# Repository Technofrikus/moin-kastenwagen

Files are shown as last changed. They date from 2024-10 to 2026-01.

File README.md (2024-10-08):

# Moinboards Kastenwagen Alu PCB

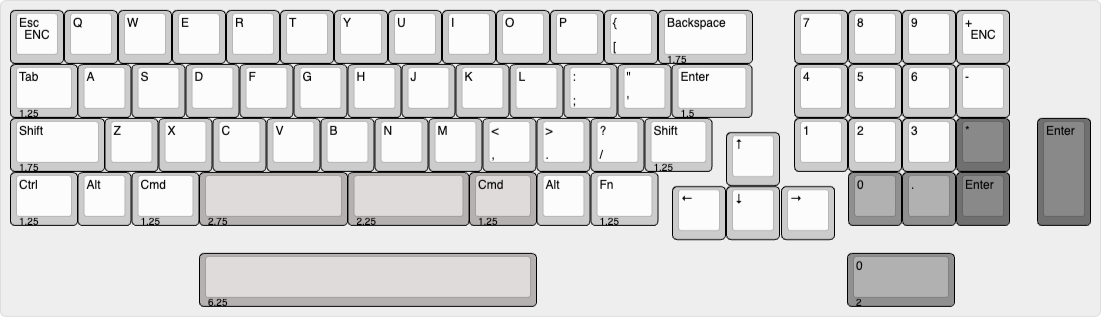
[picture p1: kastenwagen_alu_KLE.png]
Kastenwagen Alu KLE


Kastenwagen Alu is based on the [Kastenwagen 1840 by NoPunin10did](https://github.com/nopunin10did/kastenwagen/tree/main). It is a 40% keyboard with a mini-numpad and dedicated arrows. The main alpha block is 13.75u long, allowing for more dedicated punctuation keys (or non-English letters) to be paired with common Minivan-like mod keys.

- Keyboard Maintainer: [Technofrikus](https://github.com/Technofrikus) from [Moinboards](https://moinboards.de)
- Onboard STM32 MCU
- Based on the original PCB by NoPunin10did, but basically completely new and NOT compatible with the previous (printed) Kastenwagen case or PCB.
- Works with VIAL

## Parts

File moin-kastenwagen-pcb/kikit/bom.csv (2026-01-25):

Reference | MPN | Qty | Original | Value | Purchase Link | DNP | LCSC | Manufacturer
BOOT1 | TS-1187A-B-A-B | 1 | N | SW_SPST | https://www.lcsc.com/product-detail/C318884.html?s_z=n_C318884 |  | C318884 | XKB Connection
C1,C2,C4,C7,C9,C10,C13,C14,C15,C16,C17,C18,C19,C20,C21,C22,C23,C24,C25,C26,C27,C28,C29,C30,C31,C32,C33,C34,C35,C36,C37,C38,C39,C40,C41,C42,C43,C44,C45,C46 | CL05B104KB54PNC | 40 | N | 100nF | https://www.lcsc.com/product-detail/C307331.html?s_z=n_C307331 |  | C307331 | Samsung Electro-Mechanics
C3,C8 | CL05A475MP5NRNC | 2 | N | 4.7uF | https://www.lcsc.com/product-detail/C23733.html?s_z=n_C23733 |  | C23733 | Samsung Electro-Mechanics
C5 | CL05B103KB5NNNC | 1 | N | 10nF | https://www.lcsc.com/product-detail/C15195.html?s_z=n_C15195 |  | C15195 | Samsung Electro-Mechanics
C6,C11,C12 | CL05A105KA5NQNC | 3 | N | 1uF | https://www.lcsc.com/product-detail/C52923.html?s_z=n_C52923 |  | C52923 | Samsung Electro-Mechanics
D1,D2,D3,D4,D5,D6,D7,D8,D9,D10,D11,D12,D13,D14,D15,D16,D17,D18,D19,D20,D21,D22,D23,D24,D25,D26,D27,D28,D29,D30,D31,D32,D33,D34,D35,D36,D37,D38 | BAV70 | 38 | N | BAV70 | https://www.lcsc.com/product-detail/C68978.html?s_z=n_C68978 |  | C68978 | JSCJ
F1 | ASMD1206-150 | 1 | N | 500mA | https://www.lcsc.com/product-detail/C135341.html?s_z=n_C135341 |  | C135341 | JDTfuse
J1 | 781710004 | 1 | Y | X1224WRS-04-LPV01 | https://www.lcsc.com/product-detail/C588524.html?s_z=n_C588524 |  | C588524 | Molex
LED1,LED2,LED3,LED4,LED5,LED6,LED7,LED8,LED9,LED10,LED11,LED12,LED13,LED14,LED15,LED16,LED17,LED18,LED19,LED20,LED21,LED22,LED23,LED24,LED25,LED26,LED27,LED28,LED29,LED30,LED31,LED32,LED33,LED34 | XL-1010RGBC-2812B | 34 | Y | TF_WS2812_1010 | https://www.lcsc.com/product-detail/C5349953.html?s_z=n_C5349953 |  | C5349953 | XINGLIGHT
R1,R2 | FRC0402J512 TS | 2 | N | 5.1k | https://www.lcsc.com/product-detail/C2906948.html |  | C2906948 | FOJAN
R3,R4 | RT0402FRE07500RL | 2 | N | 500 | https://www.lcsc.com/product-detail/C6460545.html |  | C6460545 | YAGEO
U1 | STM32F072CBT6 | 1 | Y | STM32F072CBT6 | https://www.lcsc.com/product-detail/C81720.html?s_z=n_STM32F072CBT6 |  | C81720 | ST
U2 | PRTR5V0U2X | 1 | N | PRTR5V0U2X | https://www.lcsc.com/product-detail/C2827688.html?s_z=n_C2827688 |  | C2827688 | TECH PUBLIC
U3 | XC6206P332MR-G | 1 | N | XC6206PxxxMR-Regulator_Linear | https://www.lcsc.com/product-detail/C5446.html?s_z=n_C5446 |  | C5446 | TOREX
U4 | SN74LVC1T45DRLR | 1 | N | SN74LVC1T45DRL | https://www.lcsc.com/product-detail/C352970.html?s_z=n_SN74LVC1T45DRL |  | C352970 | TI

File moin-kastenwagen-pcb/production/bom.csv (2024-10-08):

Designator | Footprint | Quantity | Value | LCSC Part #
BOOT1 | SW_SPST_TL3342 | 1 | SW_SPST
C1, C2, C43, C45, C48, C8 | 0402 | 6 | 100nF | C307331
C10, C9 | 0402 | 2 | 1uF | C307331
C11, C12, C13, C14, C15, C16, C17, C18, C19, C20, C21, C22, C23, C24, C25, C26, C27, C28, C29, C3, C30, C31, C32, C33, C34, C35, C36, C37, C38, C39, C4, C40, C41, C42 | 0402 | 34 | 100nF
C44, C49 | 0402 | 2 | 4.7uF | C23733
C46 | 0402 | 1 | 10nF | C15195
C47 | 0402 | 1 | 1uF | C52923
D1, D477 | SOT-23 | 2 | BAV70 | C68978
D100, D101, D120, D121, D140, D141, D160, D170, D171, D202, D203, D222, D223, D242, D243, D262, D272, D273, D304, D305, D324, D325, D344, D345, D364, D374, D375, D406, D407, D437, D446, D457 | SOT-23 | 32 | BAV70
F1 | 1206 | 1 | 500mA | C135341
J2 | Molex_Pico-EZmate_78171-0004_1x04-1MP_P1.20mm_Vertical | 1 | X1224WRS-04-LPV01 | C588524
LED1, LED10, LED11, LED12, LED13, LED14, LED15, LED16, LED17, LED18, LED19, LED2, LED20, LED21, LED22, LED23, LED24, LED25, LED26, LED27, LED28, LED29, LED3, LED30, LED31, LED32, LED33, LED34, LED4, LED5, LED6, LED7, LED8, LED9 | LED_WS2812B_1010_Xinlight | 34 | TF_WS2812_1010
MX100, MX101, MX110, MX111, MX120, MX121, MX130, MX131, MX140, MX141, MX150, MX151, MX170, MX171, MX180, MX181, MX203, MX212, MX213, MX222, MX223, MX232, MX233, MX242, MX243, MX252, MX253, MX272, MX273, MX282, MX283, MX305, MX314, MX315, MX324, MX325, MX334, MX335, MX344, MX345, MX354, MX364, MX374, MX375, MX384, MX385, MX407, MX417.275, MX417.625, MX437.225, MX447, MX457, MX467, MX476, MX477, MX477.200, MX486, MX487, MX487.200 | SW_MX_HS_CPG151101S11_1u+3d | 59 | MX-NoLED
MX160, MX304 | SW_MX_HS_CPG151101S11_1.75u+3d | 2 | MX-NoLED
MX202, MX355, MX406.125, MX416.125, MX446.125, MX456.125 | SW_MX_HS_CPG151101S11_1.25u+3d | 6 | MX-NoLED
MX262 | SW_MX_HS_CPG151101S11_1.5u_+3d | 1 | MX-NoLED
R1, R2 | 0402 | 2 | 500
R8, R9 | 0402 | 2 | 5.1k
U1 | SOT-563 | 1 | SN74LVC1T45DRL
U2 | SOT-143 | 1 | PRTR5V0U2X | C2827688
U4 | SOT-23 | 1 | XC6206PxxxMR-Regulator_Linear | C5446
U5 | LQFP-48_7x7mm_P0.5mm | 1 | STM32F072CBT6

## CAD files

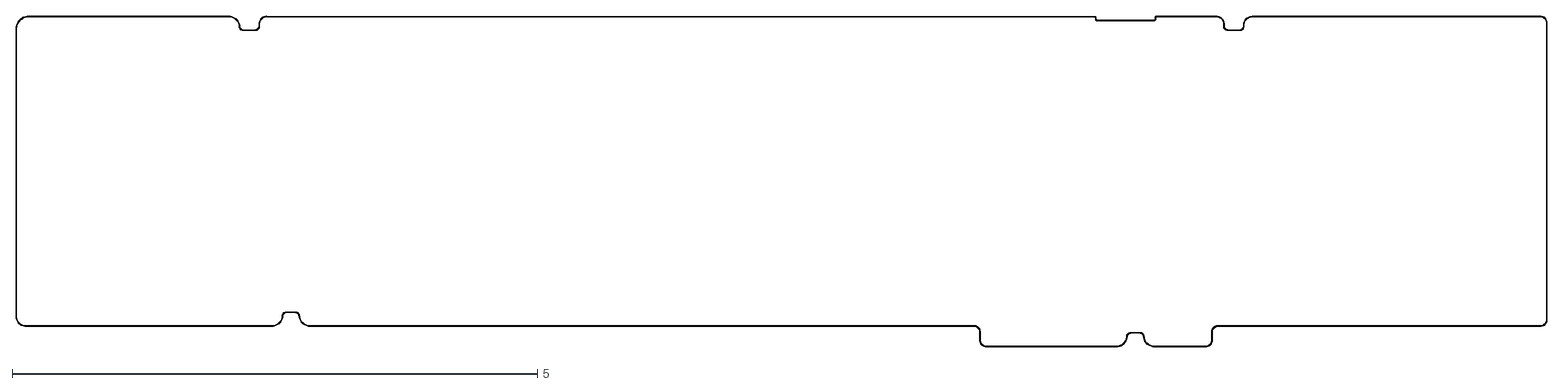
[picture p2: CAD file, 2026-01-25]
moin-kastenwagen-pcb/kastenwagen-1840-pcb-gerbers/kastenwagen-1840-pcb-Edge_Cuts.dxf
14.6 x 3.14

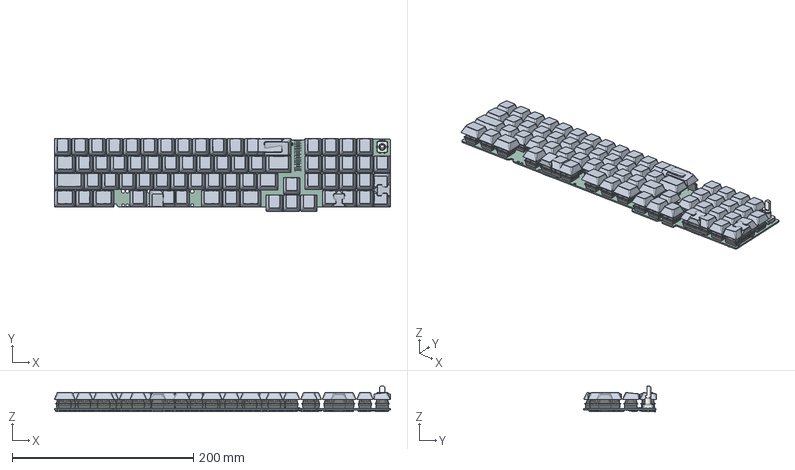
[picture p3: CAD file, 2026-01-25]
moin-kastenwagen-pcb/kastenwagen-1840-pcb.step
370.5 x 80.0 x 28.2 mm
ROT_EC11E
C_0402_1005Metric x 46
XINGLIGHT XL-1010RGBC-WS2812B Dummy v1 x 34
R_0402_1005Metric x 4
PinSocket_1x04_P2.54mm_Vertical
SOT-23 x 39
Contact x 146
Cherry_r3_100 x 63
Cherry_r3_175 x 3
Cherry_r3_125 x 6
Cherry_r3_150
SOT-563
Fuse_1206_3216Metric
SOT-143
CON_781710004
SW_SPST_TL3342
LQFP-48_7x7mm_P0.5mm
kastenwagen-1840-pcb_PCB

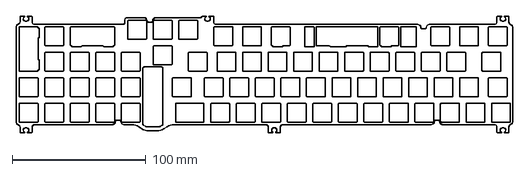
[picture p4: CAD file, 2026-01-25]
moin-kastenwagen-plate/Plate Outline 5row.dxf
370.5 x 87.1 mm

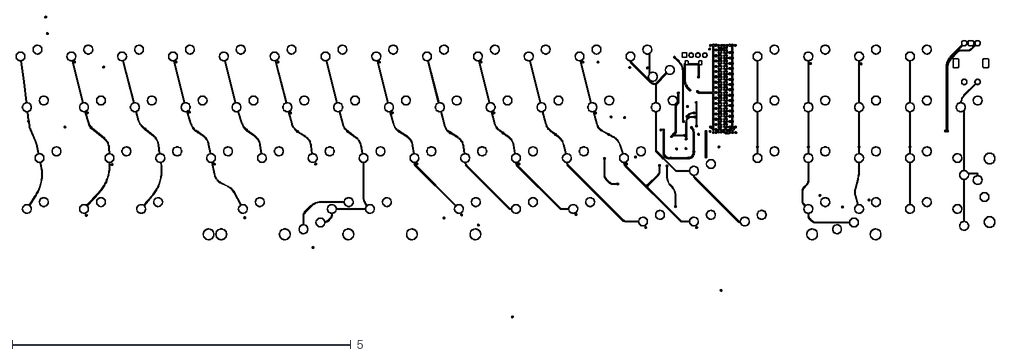
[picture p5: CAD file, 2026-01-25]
moin-kastenwagen-pcb/kastenwagen-1840-pcb-gerbers/kastenwagen-1840-pcb-F_Cu.dxf
14.4 x 4.45

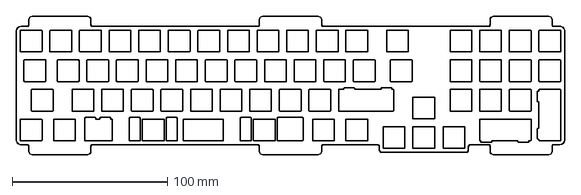
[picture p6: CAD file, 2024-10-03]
moin-kastenwagen-plate/plate.dxf
352.8 x 89.0 mm

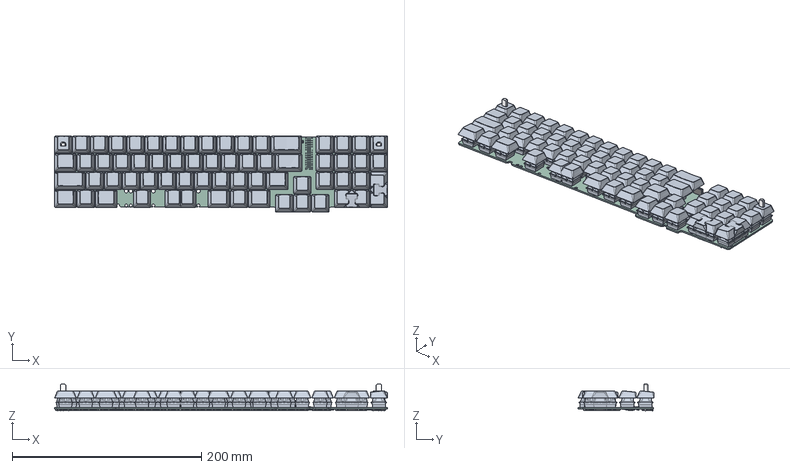
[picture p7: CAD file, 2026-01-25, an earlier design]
archive/moin-kastenwagen-pcb 5col/kastenwagen-1840-pcb.step
351.7 x 80.0 x 28.2 mm
(Unsaved) x 2
C_0402_1005Metric x 46
XINGLIGHT XL-1010RGBC-WS2812B Dummy v1 x 34
R_0402_1005Metric x 4
PinSocket_1x04_P254mm_Vertical
SOT_23 x 35
Kailh Hotswap v2 x 68
cherry mx v28 x 68
r3_100 x 59
r3_175 x 2
r3_125 x 6
r3_150
SOT_563
Fuse_1206_3216Metric
SOT_143
CON_781710004 v2
SW_SPST_TL3342
LQFP_48_7x7mm_P05mm
kastenwagen-1840-pcb_PCB

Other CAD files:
moin-kastenwagen-pcb/kastenwagen-1840-pcb-gerbers/kastenwagen-1840-pcb-F_Silkscreen.dxf

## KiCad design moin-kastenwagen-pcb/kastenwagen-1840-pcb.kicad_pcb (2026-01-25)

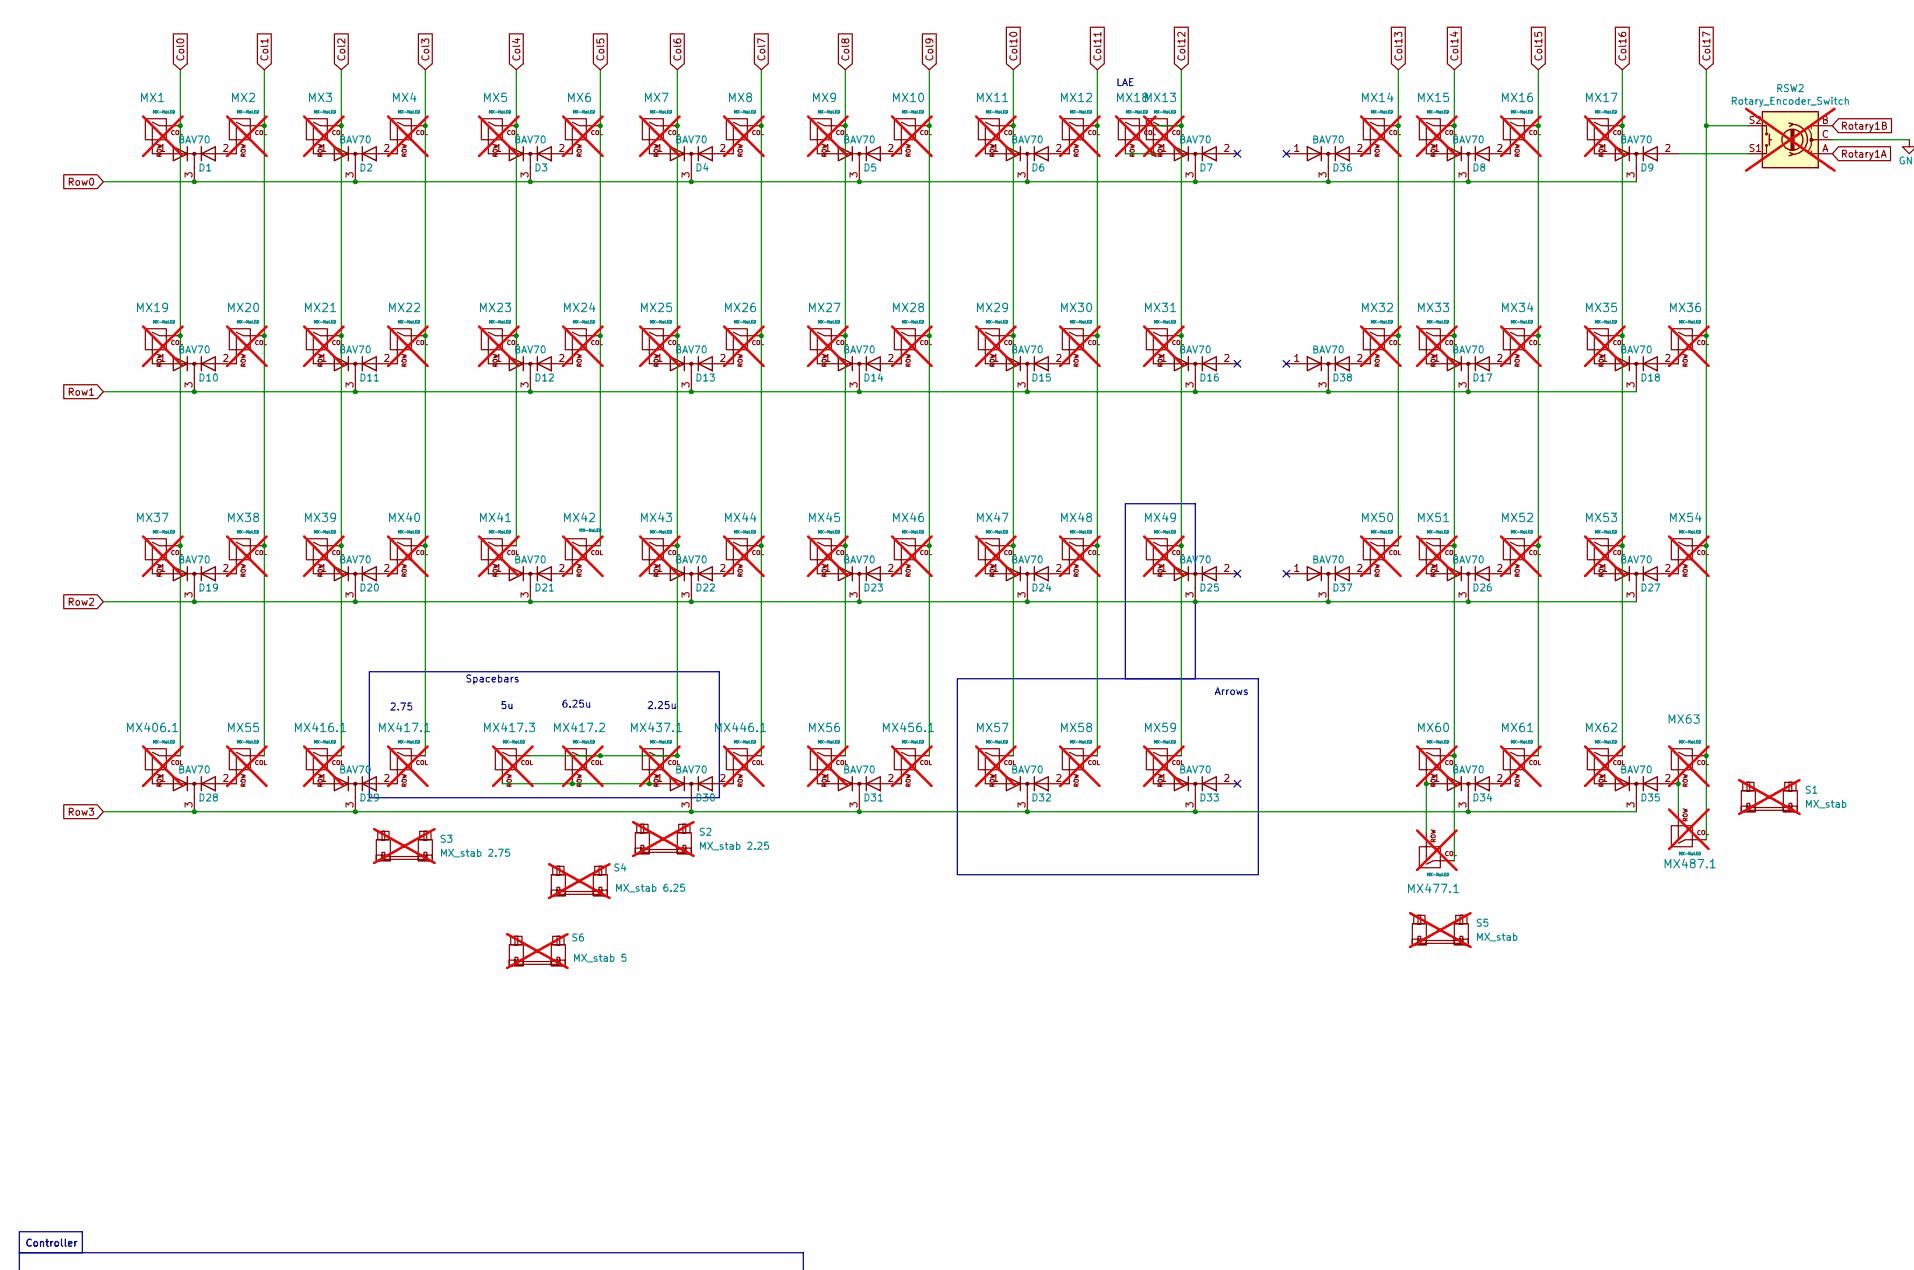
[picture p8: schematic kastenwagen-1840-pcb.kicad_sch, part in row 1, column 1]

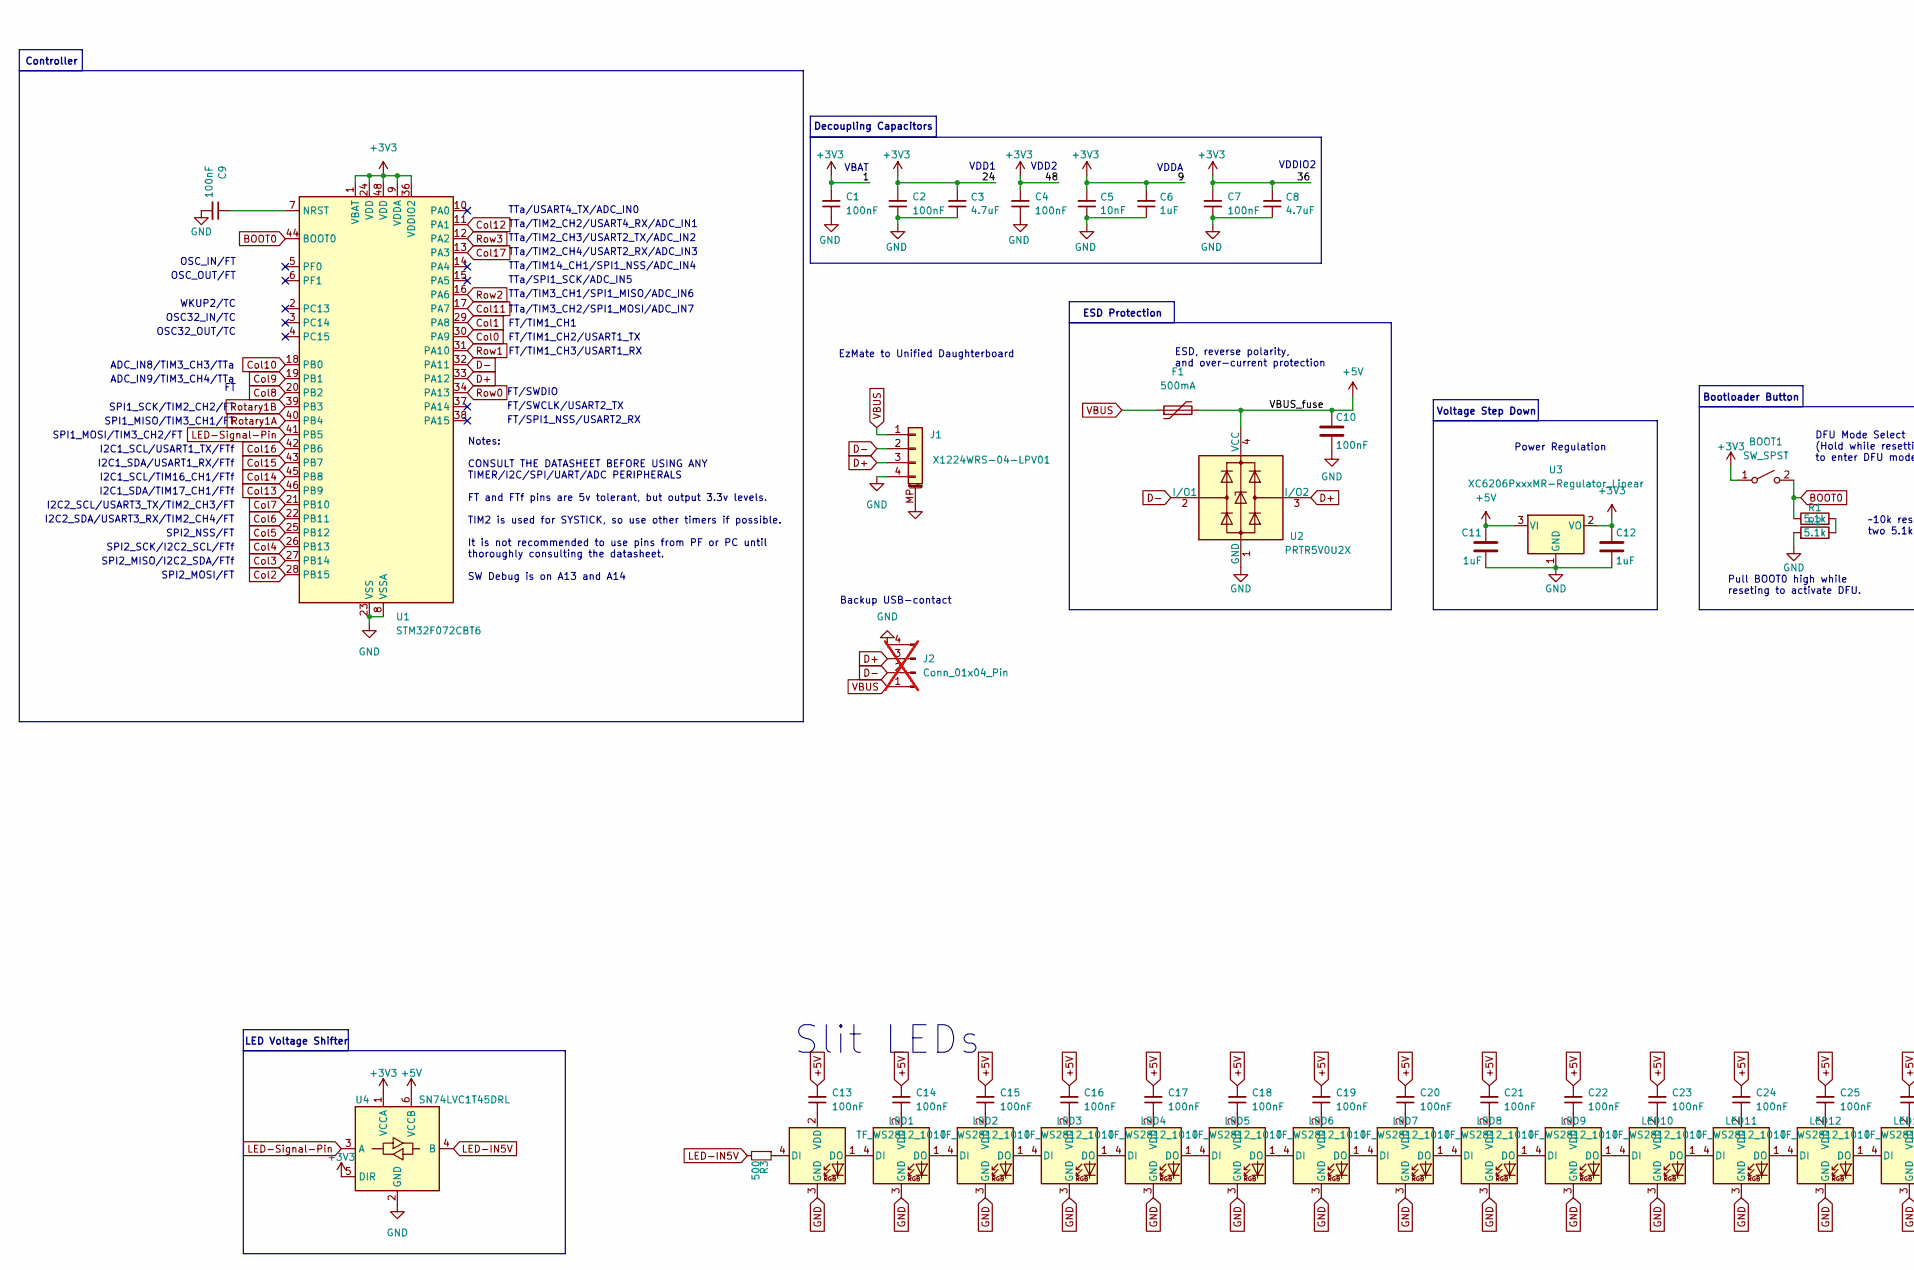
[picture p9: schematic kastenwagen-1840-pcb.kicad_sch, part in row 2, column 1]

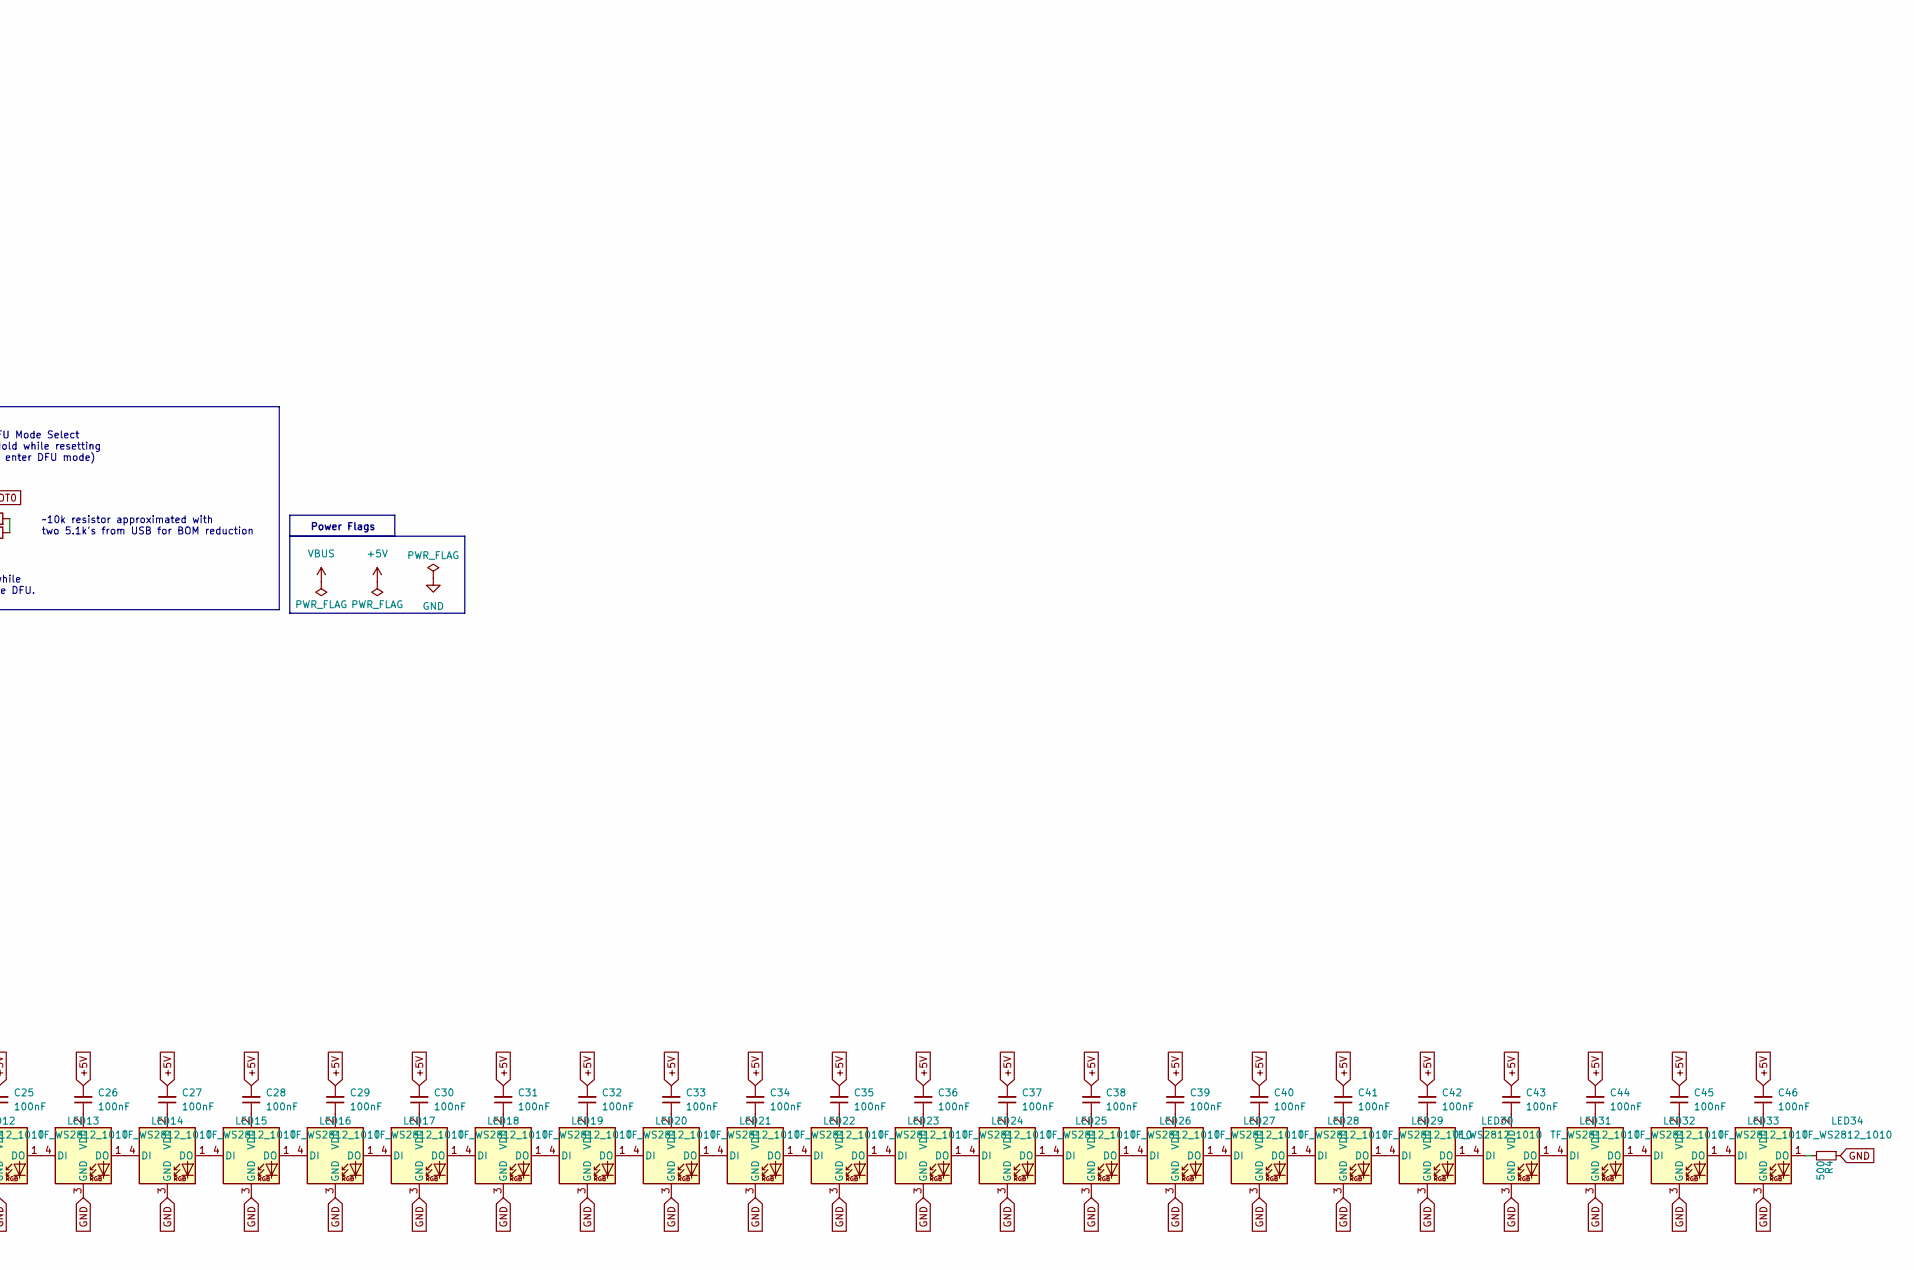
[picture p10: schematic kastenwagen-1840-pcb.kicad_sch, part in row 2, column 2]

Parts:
BOOT1: SW_SPST; SW_SPST_TL3342; Mfr Part TS-1187A-B-A-B; LCSC C318884
C1, C2, C4, C7, C9, C10, C13, C14, C15, C16, C17, C18, C19, C20, C21, C22, C23, C24, C25, C26, C27, C28, C29, C30, C31, C32, C33, C34, C35, C36, C37, C38, C39, C40, C41, C42, C43, C44, C45, C46: 100nF; C_0402_1005Metric; MPN CL05B104KB54PNC; LCSC C307331
C3, C8: 4.7uF; C_0402_1005Metric; MPN CL05A475MP5NRNC; LCSC C23733
C5: 10nF; C_0402_1005Metric; MPN CL05B103KB5NNNC; LCSC C15195
C6, C11, C12: 1uF; C_0402_1005Metric; MPN CL05A105KA5NQNC; LCSC C52923
D1, D2, D3, D4, D5, D6, D7, D8, D9, D10, D11, D12, D13, D14, D15, D16, D17, D18, D19, D20, D21, D22, D23, D24, D25, D26, D27, D28, D29, D30, D31, D32, D33, D34, D35, D36, D37, D38: BAV70; SOT-23; MPN BAV70; LCSC C68978
F1: 500mA; Fuse_1206_3216Metric; MPN ASMD1206-150; LCSC C135341
J1: X1224WRS-04-LPV01; Molex_Pico-EZmate_78171-0004_1x04-1MP_P1.20mm_Vertical; Manufacturer Part Number 781710004; LCSC C588524
J2: Conn_01x04_Pin; PinSocket_1x04_P2.54mm_Vertical; not fitted
LED1, LED2, LED3, LED4, LED5, LED6, LED7, LED8, LED9, LED10, LED11, LED12, LED13, LED14, LED15, LED16, LED17, LED18, LED19, LED20, LED21, LED22, LED23, LED24, LED25, LED26, LED27, LED28, LED29, LED30, LED31, LED32, LED33, LED34: TF_WS2812_1010; LED_WS2812B_1010_Xinlight; MPN XL-1010RGBC-2812B; LCSC C5349953
MX1, MX2, MX3, MX4, MX5, MX6, MX7, MX8, MX9, MX10, MX11, MX12, MX14, MX15, MX16, MX17, MX20, MX21, MX22, MX23, MX24, MX25, MX26, MX27, MX28, MX29, MX30, MX32, MX33, MX34, MX35, MX36, MX38, MX39, MX40, MX41, MX42, MX43, MX44, MX45, MX46, MX47, MX49, MX50, MX51, MX52, MX53, MX54, MX55, MX56, MX57, MX58, MX59, MX60, MX61, MX62, MX63, MX417.1, MX417.2, MX417.3, MX437.1, MX477.1, MX487.1: MX-NoLED; SW_MX_HS_CPG151101S11_1u+3d; not fitted
MX13, MX37: MX-NoLED; SW_MX_HS_CPG151101S11_1.75u+3d; not fitted
MX18: MX-NoLED; SW_MX_1u; not fitted
MX19, MX48, MX406.1, MX416.1, MX446.1, MX456.1: MX-NoLED; SW_MX_HS_CPG151101S11_1.25u+3d; not fitted
MX31: MX-NoLED; SW_MX_HS_CPG151101S11_1.5u_+3d; not fitted
R1, R2: 5.1k; R_0402_1005Metric; MPN FRC0402J512 TS; LCSC C2906948
R3, R4: 500; R_0402_1005Metric; MPN RT0402FRE07500RL; LCSC C6460545
RSW2: Rotary_Encoder_Switch; ROT_Alps_EC11E-Switch; not fitted
S1, S5: MX_stab; STAB_MX_P_2u; not fitted
S2: MX_stab 2.25; STAB_MX_P_2.25u_sizelabel; not fitted
S3: MX_stab 2.75; STAB_MX_P_2.75u_sizelabel; not fitted
S4: MX_stab 6.25; STAB_MX_P_6.25u_sizelabel; not fitted
S6: MX_stab 5; MXOnly-5U-NoSwitch; not fitted
U1: STM32F072CBT6; LQFP-48_7x7mm_P0.5mm; MPN STM32F072CBT6; LCSC C81720
U2: PRTR5V0U2X; SOT-143; MPN PRTR5V0U2X; LCSC C2827688
U3: XC6206PxxxMR-Regulator_Linear; SOT-23; MPN XC6206P332MR-G; LCSC C5446
U4: SN74LVC1T45DRL; SOT-563; MPN SN74LVC1T45DRLR; LCSC C352970

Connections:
+3V3: BOOT1.1 (A), C1.2, C2.2, C3.2, C4.2, C5.2, C6.2, C7.2, C8.2, C12.1, U1.1 (VBAT), U1.9 (VDDA), U1.24 (VDD), U1.36 (VDDIO2), U1.48 (VDD), U3.2 (VO), U4.1 (VCCA), U4.5 (DIR)
+5V: C10.1, C11.1, C13.2, C14.2, C15.2, C16.2, C17.2, C18.2, C19.2, C20.2, C21.2, C22.2, C23.2, C24.2, C25.2, C26.2, C27.2, C28.2, C29.2, C30.2, C31.2, C32.2, C33.2, C34.2, C35.2, C36.2, C37.2, C38.2, C39.2, C40.2, C41.2, C42.2, C43.2, C44.2, C45.2, C46.2, F1.2, U2.4 (VCC), U3.3 (VI), U4.6 (VCCB)
BOOT0: BOOT1.2 (B), R1.1, U1.44 (BOOT0)
Col0: MX1.1 (COL), MX19.1 (COL), MX37.1 (COL), MX406.1.1 (COL), U1.30 (PA9)
Col1: MX2.1 (COL), MX20.1 (COL), MX38.1 (COL), MX55.1 (COL), U1.29 (PA8)
Col2: MX3.1 (COL), MX21.1 (COL), MX39.1 (COL), MX416.1.1 (COL), U1.28 (PB15)
Col3: MX4.1 (COL), MX22.1 (COL), MX40.1 (COL), MX417.1.1 (COL), U1.27 (PB14)
Col4: MX5.1 (COL), MX23.1 (COL), MX41.1 (COL), U1.26 (PB13)
Col5: MX6.1 (COL), MX24.1 (COL), MX42.1 (COL), U1.25 (PB12)
Col6: MX7.1 (COL), MX25.1 (COL), MX43.1 (COL), MX417.2.1 (COL), MX417.3.1 (COL), MX437.1.1 (COL), U1.22 (PB11)
Col7: MX8.1 (COL), MX26.1 (COL), MX44.1 (COL), MX446.1.1 (COL), U1.21 (PB10)
Col8: MX9.1 (COL), MX27.1 (COL), MX45.1 (COL), MX56.1 (COL), U1.20 (PB2)
Col9: MX10.1 (COL), MX28.1 (COL), MX46.1 (COL), MX456.1.1 (COL), U1.19 (PB1)
Col10: MX11.1 (COL), MX29.1 (COL), MX47.1 (COL), MX57.1 (COL), U1.18 (PB0)
Col11: MX12.1 (COL), MX30.1 (COL), MX48.1 (COL), MX58.1 (COL), U1.17 (PA7)
Col12: MX13.1 (COL), MX18.1 (COL), MX31.1 (COL), MX49.1 (COL), MX59.1 (COL), U1.11 (PA1)
Col13: MX14.1 (COL), MX32.1 (COL), MX50.1 (COL), U1.46 (PB9)
Col14: MX15.1 (COL), MX33.1 (COL), MX51.1 (COL), MX60.1 (COL), MX477.1.1 (COL), U1.45 (PB8)
Col15: MX16.1 (COL), MX34.1 (COL), MX52.1 (COL), MX61.1 (COL), U1.43 (PB7)
Col16: MX17.1 (COL), MX35.1 (COL), MX53.1 (COL), MX62.1 (COL), U1.42 (PB6)
Col17: MX36.1 (COL), MX54.1 (COL), MX63.1 (COL), MX487.1.1 (COL), RSW2.S2, U1.13 (PA3)
D+: J1.3, J2.3, U1.33 (PA12), U2.3 (I/O2)
D-: J1.2, J2.2, U1.32 (PA11), U2.2 (I/O1)
GND: C1.1, C2.1, C3.1, C4.1, C5.1, C6.1, C7.1, C8.1, C9.2, C10.2, C11.2, C12.2, J1.4, J1.MP (MountPin), J2.4, LED1.3 (GND), LED2.3 (GND), LED3.3 (GND), LED4.3 (GND), LED5.3 (GND), LED6.3 (GND), LED7.3 (GND), LED8.3 (GND), LED9.3 (GND), LED10.3 (GND), LED11.3 (GND), LED12.3 (GND), LED13.3 (GND), LED14.3 (GND), LED15.3 (GND), LED16.3 (GND), LED17.3 (GND), LED18.3 (GND), LED19.3 (GND), LED20.3 (GND), LED21.3 (GND), LED22.3 (GND), LED23.3 (GND), LED24.3 (GND), LED25.3 (GND), LED26.3 (GND), LED27.3 (GND), LED28.3 (GND), LED29.3 (GND), LED30.3 (GND), LED31.3 (GND), LED32.3 (GND), LED33.3 (GND), LED34.3 (GND), R2.2, R4.1, RSW2.C, U1.8 (VSSA), U1.23 (VSS), U1.35 (VSS), U1.47 (VSS), U2.1 (GND), U3.1 (GND), U4.2 (GND)
LED-IN5V: R3.2, U4.4 (B)
LED-Signal-Pin: U1.41 (PB5), U4.3 (A)
unnamed: D9.2 (A), RSW2.S1
unnamed: LED1.4 (DI), R3.1
unnamed: LED1.1 (DO), LED2.4 (DI)
unnamed: C13.1, LED1.2 (VDD)
unnamed: LED2.1 (DO), LED3.4 (DI)
unnamed: C14.1, LED2.2 (VDD)
unnamed: LED3.1 (DO), LED4.4 (DI)
unnamed: C15.1, LED3.2 (VDD)
unnamed: LED4.1 (DO), LED5.4 (DI)
unnamed: C16.1, LED4.2 (VDD)
unnamed: LED5.1 (DO), LED6.4 (DI)
unnamed: C17.1, LED5.2 (VDD)
unnamed: LED6.1 (DO), LED7.4 (DI)
unnamed: C18.1, LED6.2 (VDD)
unnamed: LED7.1 (DO), LED8.4 (DI)
unnamed: C19.1, LED7.2 (VDD)
unnamed: LED8.1 (DO), LED9.4 (DI)
unnamed: C20.1, LED8.2 (VDD)
unnamed: C21.1, LED9.2 (VDD)
unnamed: LED9.1 (DO), LED10.4 (DI)
unnamed: LED10.1 (DO), LED11.4 (DI)
unnamed: C22.1, LED10.2 (VDD)
unnamed: LED11.1 (DO), LED12.4 (DI)
unnamed: C23.1, LED11.2 (VDD)
unnamed: LED12.1 (DO), LED13.4 (DI)
unnamed: C24.1, LED12.2 (VDD)
unnamed: LED13.1 (DO), LED14.4 (DI)
unnamed: C25.1, LED13.2 (VDD)
unnamed: LED14.1 (DO), LED15.4 (DI)
unnamed: C26.1, LED14.2 (VDD)
unnamed: LED15.1 (DO), LED16.4 (DI)
unnamed: C27.1, LED15.2 (VDD)
unnamed: LED16.1 (DO), LED17.4 (DI)
unnamed: C28.1, LED16.2 (VDD)
unnamed: LED17.1 (DO), LED18.4 (DI)
unnamed: C29.1, LED17.2 (VDD)
unnamed: LED18.1 (DO), LED19.4 (DI)
unnamed: C30.1, LED18.2 (VDD)
unnamed: LED19.1 (DO), LED20.4 (DI)
unnamed: C31.1, LED19.2 (VDD)
unnamed: LED20.1 (DO), LED21.4 (DI)
unnamed: C32.1, LED20.2 (VDD)
unnamed: LED21.1 (DO), LED22.4 (DI)
unnamed: C33.1, LED21.2 (VDD)
unnamed: LED22.1 (DO), LED23.4 (DI)
unnamed: C34.1, LED22.2 (VDD)
unnamed: LED23.1 (DO), LED24.4 (DI)
unnamed: C35.1, LED23.2 (VDD)
unnamed: LED24.1 (DO), LED25.4 (DI)
unnamed: C36.1, LED24.2 (VDD)
unnamed: LED25.1 (DO), LED26.4 (DI)
unnamed: C37.1, LED25.2 (VDD)
unnamed: LED26.1 (DO), LED27.4 (DI)
unnamed: C38.1, LED26.2 (VDD)
unnamed: LED27.1 (DO), LED28.4 (DI)
unnamed: C39.1, LED27.2 (VDD)
unnamed: LED28.1 (DO), LED29.4 (DI)
unnamed: C40.1, LED28.2 (VDD)
unnamed: LED29.1 (DO), LED30.4 (DI)
unnamed: C41.1, LED29.2 (VDD)
unnamed: LED30.1 (DO), LED31.4 (DI)
unnamed: C42.1, LED30.2 (VDD)
unnamed: LED31.1 (DO), LED32.4 (DI)
unnamed: C43.1, LED31.2 (VDD)
unnamed: LED32.1 (DO), LED33.4 (DI)
unnamed: C44.1, LED32.2 (VDD)
unnamed: LED33.1 (DO), LED34.4 (DI)
unnamed: C45.1, LED33.2 (VDD)
unnamed: LED34.1 (DO), R4.2
unnamed: C46.1, LED34.2 (VDD)
unnamed: D1.1 (A), MX1.2 (ROW)
unnamed: D1.2 (A), MX2.2 (ROW)
unnamed: D2.1 (A), MX3.2 (ROW)
unnamed: D2.2 (A), MX4.2 (ROW)
unnamed: D3.1 (A), MX5.2 (ROW)
unnamed: D3.2 (A), MX6.2 (ROW)
unnamed: D4.1 (A), MX7.2 (ROW)
unnamed: D4.2 (A), MX8.2 (ROW)
unnamed: D5.1 (A), MX9.2 (ROW)
unnamed: D5.2 (A), MX10.2 (ROW)
unnamed: D6.1 (A), MX11.2 (ROW)
unnamed: D6.2 (A), MX12.2 (ROW)
unnamed: D7.1 (A), MX13.2 (ROW), MX18.2 (ROW)
unnamed: D36.2 (A), MX14.2 (ROW)
unnamed: D8.1 (A), MX15.2 (ROW)
unnamed: D8.2 (A), MX16.2 (ROW)
unnamed: D9.1 (A), MX17.2 (ROW)
unnamed: D10.1 (A), MX19.2 (ROW)
unnamed: D10.2 (A), MX20.2 (ROW)
unnamed: D11.1 (A), MX21.2 (ROW)
unnamed: D11.2 (A), MX22.2 (ROW)
unnamed: D12.1 (A), MX23.2 (ROW)
unnamed: D12.2 (A), MX24.2 (ROW)
unnamed: D13.1 (A), MX25.2 (ROW)
unnamed: D13.2 (A), MX26.2 (ROW)
unnamed: D14.1 (A), MX27.2 (ROW)
unnamed: D14.2 (A), MX28.2 (ROW)
unnamed: D15.1 (A), MX29.2 (ROW)
unnamed: D15.2 (A), MX30.2 (ROW)
unnamed: D16.1 (A), MX31.2 (ROW)
unnamed: D38.2 (A), MX32.2 (ROW)
unnamed: D17.1 (A), MX33.2 (ROW)
unnamed: D17.2 (A), MX34.2 (ROW)
unnamed: D18.1 (A), MX35.2 (ROW)
unnamed: D18.2 (A), MX36.2 (ROW)
unnamed: D19.1 (A), MX37.2 (ROW)
unnamed: D19.2 (A), MX38.2 (ROW)
unnamed: D20.1 (A), MX39.2 (ROW)
unnamed: D20.2 (A), MX40.2 (ROW)
unnamed: D21.1 (A), MX41.2 (ROW)
unnamed: D21.2 (A), MX42.2 (ROW)
unnamed: D22.1 (A), MX43.2 (ROW)
unnamed: D22.2 (A), MX44.2 (ROW)
unnamed: D23.1 (A), MX45.2 (ROW)
unnamed: D23.2 (A), MX46.2 (ROW)
unnamed: D24.1 (A), MX47.2 (ROW)
unnamed: D24.2 (A), MX48.2 (ROW)
unnamed: D25.1 (A), MX49.2 (ROW)
unnamed: D37.2 (A), MX50.2 (ROW)
unnamed: D26.1 (A), MX51.2 (ROW)
unnamed: D26.2 (A), MX52.2 (ROW)
unnamed: D27.1 (A), MX53.2 (ROW)
unnamed: D27.2 (A), MX54.2 (ROW)
unnamed: D28.2 (A), MX55.2 (ROW)
unnamed: D31.1 (A), MX56.2 (ROW)
unnamed: D32.1 (A), MX57.2 (ROW)
unnamed: D32.2 (A), MX58.2 (ROW)
unnamed: D33.1 (A), MX59.2 (ROW)
unnamed: D34.2 (A), MX61.2 (ROW)
unnamed: D35.1 (A), MX62.2 (ROW)
unnamed: D28.1 (A), MX406.1.2 (ROW)
unnamed: D29.1 (A), MX416.1.2 (ROW)
unnamed: D29.2 (A), MX417.1.2 (ROW)
unnamed: D30.1 (A), MX417.2.2 (ROW), MX417.3.2 (ROW), MX437.1.2 (ROW)
unnamed: D30.2 (A), MX446.1.2 (ROW)
unnamed: D31.2 (A), MX456.1.2 (ROW)
unnamed: D34.1 (A), MX60.2 (ROW), MX477.1.2 (ROW)
unnamed: D35.2 (A), MX63.2 (ROW), MX487.1.2 (ROW)
unnamed: R1.2, R2.1
unnamed: C9.1, U1.7 (NRST)
Rotary1A: RSW2.A, U1.40 (PB4)
Rotary1B: RSW2.B, U1.39 (PB3)
Row0: D1.3 (K), D2.3 (K), D3.3 (K), D4.3 (K), D5.3 (K), D6.3 (K), D7.3 (K), D8.3 (K), D9.3 (K), D36.3 (K), U1.34 (PA13)
Row1: D10.3 (K), D11.3 (K), D12.3 (K), D13.3 (K), D14.3 (K), D15.3 (K), D16.3 (K), D17.3 (K), D18.3 (K), D38.3 (K), U1.31 (PA10)
Row2: D19.3 (K), D20.3 (K), D21.3 (K), D22.3 (K), D23.3 (K), D24.3 (K), D25.3 (K), D26.3 (K), D27.3 (K), D37.3 (K), U1.16 (PA6)
Row3: D28.3 (K), D29.3 (K), D30.3 (K), D31.3 (K), D32.3 (K), D33.3 (K), D34.3 (K), D35.3 (K), U1.12 (PA2)
VBUS: F1.1, J1.1, J2.1

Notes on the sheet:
WKUP2/TC
FT/TIM1_CH3/USART1_RX
TTa/TIM3_CH2/SPI1_MOSI/ADC_IN7
6.25u
Pull BOOT0 high while reseting to activate DFU.
SPI2_SCK/I2C2_SCL/FTf
TTa/SPI1_SCK/ADC_IN5
TTa/TIM14_CH1/SPI1_NSS/ADC_IN4
FT/SPI1_NSS/USART2_RX
VDD2
TTa/TIM3_CH1/SPI1_MISO/ADC_IN6
Arrows
Controller
SPI2_MISO/I2C2_SDA/FTf
EzMate to Unified Daughterboard
VBAT
Decoupling Capacitors
Bootloader Button
I2C1_SCL/USART1_TX/FTf
LAE
ADC_IN8/TIM3_CH3/TTa
Spacebars
OSC_IN/FT
ADC_IN9/TIM3_CH4/TTa
OSC32_IN/TC
SPI1_MISO/TIM3_CH1/FT
OSC32_OUT/TC
LED Voltage Shifter
I2C1_SDA/TIM17_CH1/FTf
Power Flags
SPI2_NSS/FT
Backup USB-contact
~10k resistor approximated with two 5.1k's from USB for BOM reduction
TTa/TIM2_CH4/USART2_RX/ADC_IN3
OSC_OUT/FT
FT/SWDIO
ESD, reverse polarity, and over-current protection
I2C2_SCL/USART3_TX/TIM2_CH3/FT
SPI1_MOSI/TIM3_CH2/FT
Voltage Step Down

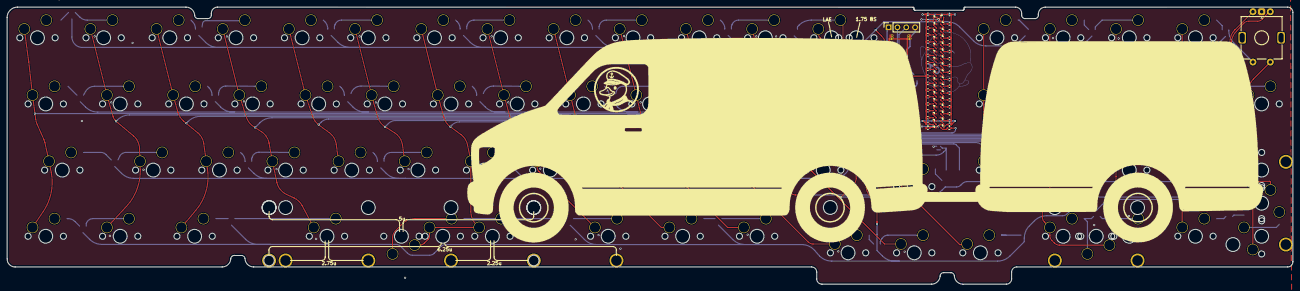
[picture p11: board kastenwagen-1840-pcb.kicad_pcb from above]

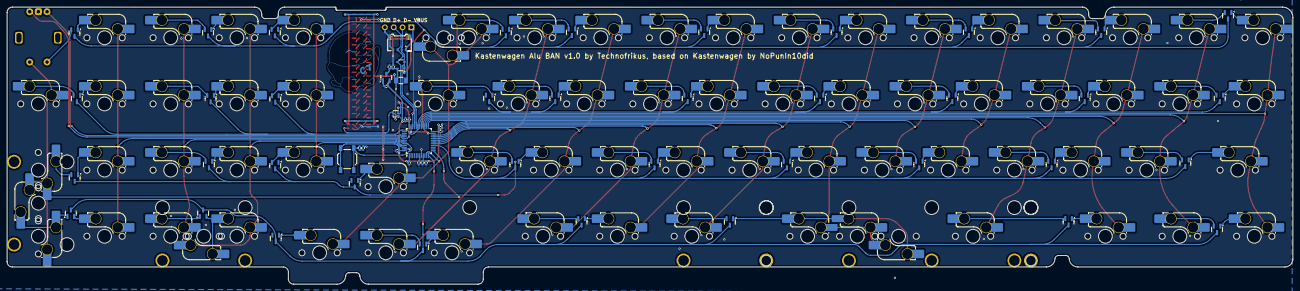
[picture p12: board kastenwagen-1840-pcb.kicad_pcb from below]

Board: 2 copper layers, 370.2 x 79.8 mm, 212 parts (132 on the bottom side), 173 nets.

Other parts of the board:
Ref**: Val**; Moinboards new logo
Ref**#2: Val**; Kastenwagen Logo - Silkscreen mirrored filled

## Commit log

2024-10-08 Untestested v1 finished. Ready for Protos.
    [kastenwagen-1840-pcb.kicad_sch]
2024-10-08 Finished Plate v1, Added correct Readme
    [moin-kastenwagen-plate.kicad_pcb]
2024-10-08 Updated gitignore to include production files
    [bom.csv, designators.csv, positions.csv]
2026-01-25 PCB und Plate bestellfertig
    [Plate Outline 5row.dxf, bom.csv, designators.csv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]
